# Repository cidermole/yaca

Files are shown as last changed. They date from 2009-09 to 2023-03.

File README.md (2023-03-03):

# Yaca: Yet Another CAN Automation

Low-level Home Automation software framework for 8-bit AVR microcontrollers using remote procedure calls.

## Embedded modules

* [module firmware sources](src/embedded)
* [message IDs and formats](src/embedded/ids.txt)

## PC software

Gateway and x86 services

* [CAN/TCP gateway](src/x86/yaca-gw)
* [time service](src/x86/yaca-timed)
* [remote bootloader programmer](src/x86/yaca-flash)
* [web dashboard](web)

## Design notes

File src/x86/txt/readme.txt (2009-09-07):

-> combine Switch.xml (auto-generated) and Switch1.xml (could have another name, given on command line) to an eeprom source file uint8_t EEMEM asdf[512] = { ... }; , compile and objcopy to obtain an eeprom hex. program that into node id given.

avr-gcc -mmcu=atmega8 -o test.o test.c -c
avr-objcopy -j .eeprom --set-section-flags=.eeprom="alloc,load" --change-section-lma .eeprom=0 -O ihex test.o main.eep

Bootstrap of remote call headers (RSwitch.h)
- Include a Messages.h with
	#define SendMessage(a, b)
- If remote call header file (RSwitch.h) doesn't exist yet, create...
- Compile the source (Switch.C)
- Generate the remote call headers (RSwitch.h)
- Include a normal Messages.h
- Compile again

avr-gcc -L/usr/lib/yaca RSwitch.o Switch.o ftable.o -Wl,-T linkerscript -lyaca -lyaca-client
avr-objcopy -O ihex -R .eeprom a.out a.hex

/home/david/Code/svn-yaca/yaca-x86/ycflash/trunk/build/main a.hex
/home/david/Code/svn-yaca/yaca-x86/ycflash/branches/yctr/build/main 1 0 0E

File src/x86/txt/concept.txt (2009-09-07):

todo PC
-------
- ../main Switch --> createRemoteHeader, createSendCode (gen. flash fct ptr), invoke avr-gcc on Switch.C

bootloader
----------
has unique CAN ID hardcoded in flash (separete source file generated and linked to bootloader), number should be printed (etched?) on PCB and on "case"

master
------
CAN-ID of master communication is 0x00000001 - stored in EEPROM, can be changed

if questioned (RTR master ID), master broadcasts the network ID (serial no. of master - 6 bytes)
if nodes detect a new network, the current IDs are not used but the master is informed that "new" nodes are on the bus.

the master issues CAN IDs for all incoming messages. outgoing message ids are read from eeprom too (generate config gui possibilities from commented eeprom source file?)

master may synchronize its clock to power grid frequency

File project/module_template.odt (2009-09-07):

# Module name

Generic module description: Power switch

### Technical data

Location | Kitchen
Boot-ID (6 byte hex) | de ad ca : b1 eb ad
Firmware version | 0.01 (28.08.2008)
Hardware version | 0.01 (15.08.2008)
Hardware built | 01.09.2008

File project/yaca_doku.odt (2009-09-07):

yaca

yet another CAN automation

technical manual

# Protocol definition

## General thoughts

The message-based structure of the CAN bus is used – messages are not adressed to a node, but have a number (the CAN message ID, in the following: „CANid“) identifying their usage. yaca uses extended CANids. These are assigned dynamically by the master node. The master node is used for setup, configuration and monitoring/logging, but the system must continue working even if the master fails.

In code, messages are simply implemented as C functions with a special prefix. A pre-/postprocessor then creates header files for including in code of other nodes, a function pointer table and CANid table in EEPROM for calling the functions when a message with a matching CANid is received. On the other hand, it also creates glue code in assembler to send a message when a remote message is „called“. This implements a simple RMI (remote method invocation) system which is supposed to make the code simple and logical.

avr-gcc is little-endian, but the message parameters are reversed while packing (avr-gcc rounds param adresses to 2, but the 8 bytes param of CAN messages are just too expensive for that) before transmission, the transmitted params are big-endian. On wire, any other numbers wider than 1 byte are represented as little-endian.

Despite being message-based, yaca still uses node identifiers (6-byte Boot-IDs) in configuration messages. The Boot-ID is hardcoded into the bootloader, effectively becoming a hardware address unique for each node.

## Master communication

Configuration mode is entered using messages with a special CANid, the Master-ID. The target is identified by the Boot-ID. Configuration mode simply refers to the Temp-ID being set and enabled, see below. After entering configuration mode, the node can be referred to with the Temp-ID, making it possible to transfer more bytes per CAN message.

A possibility exists to change the Master-ID (e.g. for using yaca on a CAN bus that has foreign nodes operating too), but it should not be done if not neccessary (if the Master-ID is lost, one can't enter the bootloader anymore). See Changing the Master-ID for details.

### Temp-ID association

This message is used to enter configuration mode – this is done by sending a temporary CANid (Temp-ID) to the target node which is then used for configuration messages later on. It sets a single byte of the Temp-ID at a time. If byten is 3 (4th byte), it also enables the Temp-ID. The frame is only valid if byten is between 0 and 3. The Temp-ID may only be stored in volatile memory (it must not be held after a power cycle).

CANid | 0 | 1 | 2 | 3 | 4 | 5 | 6 | 7
Master-ID | byten | data | Boot-ID
| [0;3]

Message 1: Temp-ID association

If the master node is done with the configuration, it revokes the temporary CANid.

CANid | 0 | 1 | 2 | 3 | 4 | 5 | 6 | 7
Temp-ID | 0x01 | d.c.

Message 2: Temp-ID revocation

The node then answers with:

CANid | 0 | 1 | 2 | 3 | 4 | 5 | 6 | 7
Temp-ID | 0x02 | d.c.

Message 3: Temp-ID freed up

The master may then free up the temporary CANid internally. If the node doesn't reply, the master shouldn't free up the Temp-ID. Cleaning up is performed on Bus power-off.

### Network-ID

Each node transmits a Network-ID request on bootup, except when it receives such a request from another node (in which case it must cancel the transmission to stop flooding the bus).

CANid | 0 | 1 | 2 | 3 | 4 | 5 | 6 | 7
Master-ID | 0xFF | 0x00 | d.c.

Message 4: Network-ID request

On receipt of a Network-ID request, the master node broadcasts it, except when it wants to Hard-enter a bootloader.

CANid | 0 | 1 | 2 | 3 | 4 | 5 | 6 | 7
Master-ID | 0xFF | 0x01 | Network-ID

Message 5: Network-ID broadcast

### New nodes

If a node receives a Network-ID different from the ID stored in EEPROM, it has changed bus (it is now connected to a new bus). The node doesn't react on any stored CANids but informs the master node:

CANid | 0 | 1 | 2 | 3 | 4 | 5 | 6 | 7
Master-ID | 0xFF | 0x02 | Boot-ID

Message 6: New node

The node also tells the master node its device type:

CANid | 0 | 1 | 2 | 3 | 4 | 5 | 6 | 7
Master-ID | 0xFF | 0x03 | device type

Message 7: New node device type

When the user wishes to use the node on the new bus, the master node clears the old CANids and overwrites the Network-ID in the new node:

CANid | 0 | 1 | 2 | 3 | 4 | 5 | 6 | 7
Master-ID | 0xFF | 0x04 | Boot-ID

Message 8: Format node

### Bus power-off message

Some nodes may hold status information in volatile RAM (e.g. to conserve EEPROM write cycles). When powering off the bus on purpose, this message advises all nodes to save volatile information in non-volatile memory. After powering off the bus, the master may clear all Temp-IDs in memory.

CANid | 0 | 1 | 2 | 3 | 4 | 5 | 6 | 7
Master-ID | 0xFF | 0xFF | d.c.

Message 9: Bus power-off broadcast

### Error messages

If the bootloader detects a wrong CRC after startup, it transmits a CRC error message:

CANid | 0 | 1 | 2 | 3 | 4 | 5 | 6 | 7
Master-ID | 0xFE | 0x01 | Boot-ID

Message 10: application CRC error

When the EEPROM overflows while writing the CANid data block, the node being programmed transmits a CANid data block address overflow:

CANid | 0 | 1 | 2 | 3 | 4 | 5 | 6 | 7
Master-ID | 0xFE | 0x02 | Boot-ID

Message 11: CANid data block address overflow

### Reading/writing the CANid data block

CANid data block write message:

CANid | 0 | 1 | 2 | 3 | 4 | 5 | 6 | 7
Temp-ID | 0x02 | offset | count | data

Message 12: CANid data block write

CANids are stored in the CANid data block. The flash memory contains the neccessary function pointers. When a message is received, a loop goes through the list bytewise and matches the received CANid. An entry may contain several CANids, i.e. an additional Group-ID. The number of CANids for an entry is saved as the first byte.

CANid data block example (2 message functions): 02 01 23 45 67 12 34 56 78 01 23 45 67 89

The first message function is called when either CANid 01 23 45 67 or 12 34 56 78 is received.

It is important that the master node waits for a CANid data block write done message after writing the CANid data block with one or more data block write messages.

Single CANid read command – mi is the message index, ci the CANid sub-index (when ci is 0xFF, the command reads the count of CANids associated with a message):

CANid | 0 | 1 | 2 | 3 | 4 | 5 | 6 | 7
Temp-ID | 0x03 | mi | ci | d.c.

Message 13: Single CANid read

The node sends a CANid reply:

CANid | 0 | 1 | 2 | 3 | 4 | 5 | | 6 | 7
Temp-ID | 0x04 | CANid/count (byte 1 only) | | | | | d.c.

Message 14: CANid reply

It is also possible to make a CANid data block read:

CANid | 0 | 1 | 2 | 3 | 4 | 5 | 6 | 7
Temp-ID | 0x05 | offset | d.c.

Message 15: CANid data block read

The node sends a CANid data block reply (usually returns 7 bytes, except if the read offset was larger than EEPROM-size - CANid data block size - 7):

CANid | 0 | 1 | 2 | 3 | 4 | 5 | 6 | 7
Temp-ID | 0x06 | data

Message 16: CANid data block reply

The CANid data block is cached in RAM to be able to execute fast consecutive writes. While the cache content differs from the data stored in EEPROM, a dirty flag is set in EEPROM. When the cache is completely flushed to EEPROM, the node clears the dirty flag and transmits a CANid data block write done message.

CANid | 0 | 1 | 2 | 3 | 4 | 5 | 6 | 7
Temp-ID | 0x07 | d.c.

Message 17: CANid data block write done

### Changing the Master-ID

WARNING: If you lose the new Master-ID, you can't enter the bootloader anymore.

Out of security considerations, this message only works after Hard-entering the bootloader.

CANid | 0 | 1 | 2 | 3 | 4 | 5 | | 6 | 7
Temp-ID | 0x08 | new Master-ID | | | | | d.c.

Message 18: Change Master-ID

## Bootloader

The bootloader is used to update the firmware of a node without having to open the wall, box etc. where the node is located. It is the first program started on the microcontroller, for being able to download a new firmware even when the current firmware is bad. For this purpose, the bootloader waits a few seconds for a Temp-ID association after startup (bootloader time-out). After having received that, the bootloader will not start the application except when instructed to do so (by a Temp-ID revocation).

Before starting the firmware, the bootloader also checks its CRC-checksum to ensure firmware integrity (e.g. to detect if the firmware loading was interrupted).

### Entering the bootloader

This shall work in both application and bootloader when in configuration mode ( Temp-ID association sent). When executing the application, it jumps over to the bootloader section and tells the bootloader the current Temp-ID.

CANid | 0 | 1 | 2 | 3 | 4 | 5 | 6 | 7
Temp-ID | 0x09 | d.c.

Message 19: Enter bootloader

### Hard-entering the bootloader

If the current application firmware is bad (wrong CRC or application error which prevents entering the bootloader), the master needs to hard-enter the bootloader. This is done by powering off the bus (see Bus power-off), waiting a few seconds until the buffer caps are discharged, re-applying power to the bus, waiting for the nodes to safely power up (e.g. 1 second less than bootloader time-out) and sending a Temp-ID association to enter configuration mode. As the bootloader section runs first on powerup, the bootloader can be entered even if the application is bad.

### Entering bootloader update

WARNING: If the newly programmed bootloader is not able to download a new bootloader, you have effectively locked yourself out. Check this before updating the bootloader.

WARNING: If power fails during a bootloader update (or if the bootstrap loader is running, even when not flashing), you have bricked the bootloader.

WARNING: The bootstrap loader is like a one-way street: you instantly have to download a new bootloader after having flashed it. There is no other way out that preserves the bootloader ability.

Do not use bootloader update. Never. You have been warned.

Out of security considerations, this message only works after Hard-entering the bootloader.

CANid | 0 | 1 | 2 | 3 | 4 | 5 | 6 | 7
Temp-ID | 0x0A | d.c.

Message 20: Enter bootloader update

Bootloader update is bound to a 512 Byte bootstrap program downloaded and started first, which then in turn downloads the actual bootloader. As this program must be very simple, the current version doesn't contain CAN controller initialization. Nothing useful will start after losing power. The bootstrap loader is downloaded as 8 pages. It may be located anywhere in the bootloader section (the current one has to be programmed at (relative) page 0) but must not overwrite the last 2 pages (the actual bootloader program which should never be updated). The bootloader may or may not send a Bootloader page done message after downloading the bootstrap loader.

### Programming

The application firmware memory is divided into pages. For the size of the pages or of the application flash, refer to the NDS. The memory is updated page-wise; first, select a page, then send data until the page is full. The page will automatically be programmed once all bytes are received. While programming a page, further data is ignored. After programming, the page counter will be incremented automatically; selecting further pages is only needed when leaving out pages while programming partially. When page programming is done, the node sends a Bootloader page done message.

The following message selects a page in the flash of the microcontroller:

CANid | 0 | 1 | 2 | 3 | 4 | 5 | 6 | 7
Temp-ID | 0x0B | page [le] | | d.c.

Message 21: Bootloader page select

When downloading a bootloader, page counts as an offset from the start of the bootloader section. After a page is selected (or the page counter was incremented automatically), the master node sends the page data (the data pointer is advanced by the CAN message size):

CANid | 0 | 1 | 2 | 3 | 4 | 5 | 6 | 7
Temp-ID | 0x0C | data

Message 22: Bootloader page data

When the node has finished programming the page, it sends the following message:

CANid | 0 | 1 | 2 | 3 | 4 | 5 | 6 | 7
Temp-ID | 0x0D | d.c.

Message 23: Bootloader page done

After programming, a Temp-ID revocation tells the bootloader to calculate the application CRC.

For now, the Temp-ID is stored (fix) in EEPROM – to boot the app, the bootloader sends:

CANid | 0 | 1 | 2 | 3 | 4 | 5 | 6 | 7
Temp-ID | 0x0E | d.c.

Message 24: Boot application

# Node datasheet

The node datasheet (NDS) is an XML file containing information about a specific node firmware, e.g. message functions, EEPROM size, page size etc. These are needed by the master node.

# Message index

Message 1: Temp-ID association 3

Message 2: Temp-ID revocation 4

Message 3: Network-ID request 4

Message 4: Network-ID broadcast 4

Message 5: New node 4

Message 6: New node device type 4

Message 7: Format node 4

Message 8: Bus power-off broadcast 5

Message 9: application CRC error 5

Message 10: CANid data block address overflow 5

Message 11: CANid data block write 5

Message 12: Single CANid read 6

Message 13: CANid reply 6

Message 14: CANid data block read 6

Message 15: CANid data block reply 6

Message 16: CANid data block write done 6

Message 17: Changing the Master-ID 6

Message 18: Enter bootloader 7

Message 19: Enter bootloader update 7

Message 20: Bootloader page select 8

Message 21: Bootloader page data 8

Message 22: Bootloader page done 8

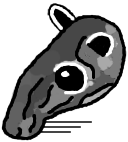
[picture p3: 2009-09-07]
project/img/yaca.png

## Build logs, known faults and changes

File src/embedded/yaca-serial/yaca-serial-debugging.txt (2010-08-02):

__vector_1: b0e - bc8 = 186 / 2 = 93 + 1 = 94 commands
  22x 1 clock-cycle command

94 * 2 - 22 = ~ 166 clock cycles

+ mcp2515_rdstatus  154
+ _read_frame  1228

= 1548 clocks    (__vector_1)
  ===========

(96.75 us @ 16 MHz)

250.000 baud ^= 40 us byte time

_spi_putc: 1/8 SPI clock of main clock -> 8 * 8 = 64 cycles (66, "gcd"(X, 3 clocks busywait)) + 5 = 71 clock cycles
                                                                                                    ===============

mcp2515_rdstatus: 12 clocks + 2 * _spi_putc (71) = 154 clocks
                                                   ==========

_read_frame: a3a - b0c = 210 / 2 = 105 + 1 = 106 commands, + for loop 637 ((20 instr + 71 _spi_putc) * 7 loops)
 47 x 1 cycle command
106 * 2 - 47 = ~ 165 clocks

+ for loop 637 (see above)
+ 6 x _spi_putc 71 = 426

= 1228 clocks
  ===========

--------------------

SPI x4   -> ~ 48 clocks per SPI byte

15 SPI bytes -> ~ 720 cycles saved, 828 remaining (103.5 us @ 8 MHz, 51.75 us @ 16 MHz)

125.000 baud ^= 80 us byte time

USART RxC interrupt (__vector_11) 722 - 76c = 74 + 2 = 76 - 6 single cycle = 70
+ fifo2_put 61

= 131 clocks  (8.19 us @ 16 MHz)
  ==========

fifo2_put: 834 - 878 = 68 + 2 = 70 - 9 single cycle = 61

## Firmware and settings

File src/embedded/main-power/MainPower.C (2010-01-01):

#include "MainPower.h"
#include "RMainPower.h"
#include <avr/io.h>
#include <avr/eeprom.h>
#include <avr/interrupt.h>
#ifndef F_CPU
#define F_CPU 8000000UL
#endif
#include <util/delay.h>
#include <inttypes.h>
#include <yaca.h>


#define OCR_VAL 200


#define ADC_U_OUT 0
#define ADC_I_IN  1
#define ADC_U_IN  2
#define ADMUX_REF ((1 << REFS1) | (1 << REFS0)) // AREF = 2.56 V


#define ST_IDLE    0
#define ST_BOOST   1
#define ST_CHARGE  2
#define ST_CHG_TOP 3


#define MILLIAMP_TO_PWM(a) (a * 255 / 100)

// TODO: soft-start (with reduced OCR_VAL) -- blew 2 A fuse without warning :-)

// PC5: red led
// PC4: green led

// PB0: charger: low-freq PWM (const. I on/off, I ~ 100 mA, we are consuming 33 mA with both LEDs)
// we are charging if we pull PB0 to 0. *do not* set PB0 to 1 (connected to base of transistor)

// PB1: PWM for step-up regulator (OC1A)

volatile uint8_t ac_power = 0, dc_maybe = 0, status_update = 0;
volatile uint16_t ac_status_scaler = 0;
volatile uint8_t charge_pwm_scaler = 0, charge_pwm = 0;
uint8_t state = ST_IDLE;
// PORTABILITY. seconds type 32-bit int overflows after 136 years, seems OK
uint32_t seconds = 0;
uint32_t chg_target = 0;
uint32_t lost_charge = 0;
uint16_t u_in, i_in;
uint8_t fifths = 0;
uint8_t no_topping = 0;

void transmit_status();

void delay_ms(uint16_t t) {
	uint16_t i;
	for(i = 0; i < t; i++)
		_delay_ms(1);
}

void red_led(uint8_t i) {
	if(i)
		PORTC |= (1 << PC5);
	else
		PORTC &= ~(1 << PC5);
}

void red_led_toggle() {
	PORTC ^= (1 << PC5);
}

void green_led(uint8_t i) {
	if(i)
		PORTC |= (1 << PC4);
	else
		PORTC &= ~(1 << PC4);
}

uint16_t adc_convert(uint8_t channel) {
	ADMUX = (channel & 0x07) | ADMUX_REF; // select channel (+ keep reference)
	ADCSRA |= (1 << ADSC) | (1 << ADIF); // start conversion, clear int flag
	while(!(ADCSRA & (1 << ADIF))); // wait for conversion

	return ADCW;
}

void adc_init() {
	ADMUX = (1 << REFS1) | (1 << REFS0);
	ADCSRA = (1 << ADEN) | (1 << ADPS2) | (1 << ADPS1); // enable ADC, prescaler = 64 (8 MHz / 64 = 125 kHz, 13 cycles per conversion ~ 100 us conversion)
	delay_ms(100); // wait for ADC to warm up
	adc_convert(0); // dummy conversion
}

void transition_idle() {
	transmit_status();
	charge_pwm = MILLIAMP_TO_PWM(35); // we consume 33 mA from battery at all times, 2 mA reserved
	red_led(0);
	green_led(1);
	state = ST_IDLE;
}

void transition_boost() {
	charge_pwm = 0; // if boosting, we have no AC - don't waste our own power
	red_led(1);
	green_led(0);
	state = ST_BOOST;
}

void transition_charge() {
	charge_pwm = MILLIAMP_TO_PWM(100); // charge with (100 - 33) = 67 mA
	yc_prepare(2008);
	yc_send(MainPower, Debug1(lost_charge));
	if((lost_charge >> 16) < 22) { // if discharge was less than 10 %, omit the topping
		no_topping = 1;
	} else {
		no_topping = 0;
	}
	chg_target = seconds + (lost_charge >> 16) * 459;
	yc_prepare(2009);
	yc_send(MainPower, Debug2(chg_target));
	red_led(1);
	green_led(1);
	state = ST_CHARGE;
}

void transition_chg_top() {
	if(no_topping) {
		transition_idle();
		return;
	}

	// low charging current is supposedly bad for batteries, so topping charge with the full current (C/28 anyways...)
	charge_pwm = MILLIAMP_TO_PWM(100); // charge with (100 - 33) = 67 mA
	chg_target = seconds + 1200; // 20 min * 67 mA = 22 mAh (1,2 %)
	green_led(1);
	// red led is blinking
	state = ST_CHG_TOP;
}

// recalculate_charge(): we were charging and lost power... recalculate lost_charge
void recalculate_charge() {
	lost_charge = (((chg_target - seconds) * 1713) / 3072) * 256;
}

void transmit_status() {
	uint8_t t_high = 0;
	uint16_t t = 0;
	
	if(state == ST_CHARGE || state == ST_CHG_TOP) {
		t_high = (chg_target - seconds) >> 16;
		t = (chg_target - seconds) & 0xFFFF;
	} else if(state == ST_BOOST) {
		t_high = lost_charge >> 16;
		t = lost_charge & 0xFFFF;
	}
	
	yc_prepare_ee(YC_EE_POWERSTATUS_ID);
	yc_send(MainPower, PowerStatus(state, u_in, i_in, t_high, t));
}

int main() {
	uint8_t tenth_count = 0;

	DDRC |= (1 << PC5) | (1 << PC4);
	DDRB |= (1 << PB1) | (1 << PB0);
	ACSR = (1 << ACBG); // Analog Comp: + is bandgap ref. = 1,23 V

	ICR1 = 256;
	TCCR1A = (1 << WGM11); // 8-bit
	TCCR1B = (1 << WGM13) | (1 << WGM12) | (1 << CS10); // prescaler 1, fast pwm
	TIMSK |= (1 << TOIE1);
	OCR1A = OCR_VAL;

	sei();
	
	ac_power = 1; // optimism rules!
	adc_init();
	
	transition_idle();
	
	while(1) {
		switch(state) {
		case ST_IDLE:
			if(!ac_power)
				transition_boost();
			break;

		case ST_BOOST:
			if(ac_power) {
				transition_charge();
			}
			break;

		case ST_CHARGE:
			if(!ac_power) {
				recalculate_charge();
				transition_boost();
				break;
			}
			if(seconds > chg_target)
				transition_chg_top();
			break;

		case ST_CHG_TOP:
			if(!ac_power) {
				transition_boost();
				break;
			}
			if(seconds > chg_target)
				transition_idle();
			break;

		default:
			break;
		}
		
		if(status_update) { // every 100 ms
			if(++tenth_count == 10) {
				seconds++;
				tenth_count = 0;
				
				if(state == ST_CHG_TOP) {
					red_led_toggle();
				}
			}
			
			u_in = adc_convert(ADC_U_IN);
			i_in = adc_convert(ADC_I_IN);
			
			if(state == ST_BOOST)
				lost_charge += i_in;
			
			if(++fifths == 2) {
				if(state != ST_IDLE)
					transmit_status();
				fifths = 0;
			}
			status_update = 0;
		}
		
		yc_dispatch_auto();
	}
	return 0;
}

void DM(Charge(uint8_t t_high, uint16_t t)) {
	transition_charge();
	chg_target = seconds + (((uint32_t) t_high) << 16) + t;
	transmit_status();
}

void DR(PowerStatus()) {
	transmit_status();
}

void enter_bootloader_hook() {
	cli();
	TCCR1A = 0;
	TCCR1B = 0;
	TCNT1 = 0;
	TIMSK = 0;
	DDRB &= ~(1 << PB0); // stop charging
	PORTC &= ~(1 << PC4); // green off
	PORTC &= ~(1 << PC5); // red off
	yc_bld_reset();
}

ISR(TIMER1_OVF_vect) {
	if(ACSR & (1 << ACO)) {
		TCCR1A |= (1 << COM1A1);
		dc_maybe = 1;
	} else {
		TCCR1A &= ~(1 << COM1A1);
	}
	
	if(ac_power) { // software PWM
		charge_pwm_scaler++;
		
		if(charge_pwm_scaler == 0) // 256 -> every 8.2 ms (122 Hz)
			DDRB |= (1 << PB0);
		
		if(charge_pwm_scaler == charge_pwm)
			DDRB &= ~(1 << PB0);
	} else {
		DDRB &= ~(1 << PB0);
	}
	
	if(++ac_status_scaler == 3125) { // every 100 ms, update AC status
		ac_status_scaler = 0;
		ac_power = !dc_maybe;
		dc_maybe = 0;
		status_update = 1;
	}
}

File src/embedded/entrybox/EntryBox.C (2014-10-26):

#include "EntryBox.h"
#include "REntryBox.h"
#include <stdint.h>
#include <yaca.h>
#include <avr/io.h>
#include <avr/interrupt.h>

#ifndef INT32_MAX
#define INT32_MAX 0x7fffffffL
#endif

/*

PB1 (OC1A): charge pump for opamps
PD0: radar sensor supply (N-channel MOSFET gate) TODO: power
PD1: battery charger from CAN-bus power to battery, /EN of LM2576
PD5: photo camera (N-channel MOSFET gate)
PD6: dummy load (N-channel MOSFET gate)
PD7: radar sensor input, pulling vs. GND

ADC0: IBAT (battery current), 6.5 mA resolution
ADC1: VBAT (battery voltage), 15 mV resolution
ADC2: ISOL (solar [charge] current), 3.25 mA resolution

  |
  v IBAT
+ |
-----  12 V lead-acid battery
 ---
  |



coulomb counter
---------------
basic resolution: U = 15 mV, I = 6.5 mA, P = 97.5 uW (microwatt)

ADC low-pass filter tau = 2 ms -> 10 ms changes relevant -> 100 Hz samplerate

12 V 7 Ah capacity fits into 32 bit
1 year's worth of microjoules don't fit

~ 10256 P units equal 1 Watt
1 year's worth of Joules fit. -> energy counting in Joules


*/

#define ADC_IBAT 0
#define ADC_VBAT 1
#define ADC_ISOL 2

#define ADMUX_REF ((1 << REFS1) | (1 << REFS0)) // internal AREF = 2.56 V with external cap

#define VBAT_REL_ERROR (-0.01) // measured and calculated
#define DUMMY_OFF_THRESHOLD_V ((uint16_t) (12.9 / 0.015 * (1+VBAT_REL_ERROR)))
#define DUMMY_ON_THRESHOLD_V ((uint16_t) (12.5 / 0.015 * (1+VBAT_REL_ERROR)))

#define CHARGE_OFF_THRESHOLD_V ((uint16_t) (13.6 / 0.015 * (1+VBAT_REL_ERROR)))
#define CHARGE_ON_THRESHOLD_V ((uint16_t) (12.1 / 0.015 * (1+VBAT_REL_ERROR)))

#define JOULE_100_PUNITS 1025641L
#define JOULE_BATTERY_FULL (12 * 7 * 3600UL)
#define MAXIMUM_POWER_OUTPUT 42 // 42: 14 V * 3 A, the expected maximum output power

void enter_bootloader_hook() {
	TCCR1A = 0;
	TCCR1B = 0;
	TCCR2 = 0;
	TIMSK = 0;
	cli();
	yc_bld_reset();
}

void init_timers() {
	OCR1A = 100; // 2 MHz / 100 = 20 kHz toggle -> 10 kHz frequency generator
	TCCR1A = (1 << COM1A0); // toggle OC1A on compare match
	TCCR1B = (1 << WGM12) | (1 << CS10); // CTC mode, top = OCR1A, prescaler = 1

	OCR2 = 156; // 2 MHz / (156 * 128) = ~ 100 Hz
	TCCR2 = (1 << WGM21) | (1 << CS22) | (1 << CS20); // CTC mode, prescaler = 128

	TIMSK = (1 << OCIE2); // enable Timer2 compare match interrupt
}

void init_adc() {
	ADMUX = ADMUX_REF; // Vref = internal 2.56 V with external cap
	ADCSRA = (1 << ADEN) | (1 << ADPS2); // ADC prescaler = 16 -> 2 MHz / 16 = 125 kHz
}

void init_ports() {
	DDRB |= (1 << PB1); // config OC1A as output (charge pump)
	DDRD |= (1 << PD6) | (1 << PD5) | (1 << PD1) | (1 << PD0); // dummy, camera, emergency charger, radar power
	PORTD |= (1 << PD7) | (1 << PD5) | (1 << PD1) | (1 << PD0); // PD7: motion relay: input with pullup, PD5: photo trigger (phone charger), PD1: emergency charger off, PD0: radar power perm. on for now
	//PORTD &= ~(1 << PD1); // temp: enable charger
}

int16_t adc_convert(uint8_t channel) {
	ADMUX = (channel & 0x07) | ADMUX_REF; // select channel (+ keep reference)
	ADCSRA |= (1 << ADSC) | (1 << ADIF); // start conversion, clear int flag
	while(!(ADCSRA & (1 << ADIF))); // wait for conversion
	return ADCW;
}

/**
 * This might be overkill, but group 4 reads together, and poll CAN inbetween (4 * 14 < 67) (shortest CAN frame: 67 bit times of 125 kHz CAN bitrate)
 */
int16_t adc_convert_avg(uint8_t channel) {
	uint8_t i, j;
	int16_t sum = 0; // 2^10 ADC resolution * (2^5 = 32 reads) possible before overrun in 16-bit signedness

	// instead of using adc_convert(), just select the channel once here.
	ADMUX = (channel & 0x07) | ADMUX_REF; // select channel (+ keep reference)

	for(j = 0; j < 8; j++) {
		for(i = 0; i < 4; i++) {
			// 8 * 4 = 32 samples average
			ADCSRA |= (1 << ADSC) | (1 << ADIF); // start conversion, clear int flag
			while(!(ADCSRA & (1 << ADIF))); // wait for conversion
			sum += ADCW;
		}
		yc_dispatch_auto();
	}

	return sum / 32;
}

int16_t ibat_offset = 538; // Ibat offset from calculations
int16_t ibat;
uint16_t vbat, isol;
int32_t sum_punit = 0;
uint32_t sum_punit_solar = 0;
uint32_t joule_battery = JOULE_BATTERY_FULL;
uint32_t joule_solar = 0;

uint32_t count = 0; // car count

uint8_t cam_force = 1; // 0: force off, 1: auto, 2: force on
uint8_t charger_force = 1; // 0: force off, 1: auto, 2: force on
uint8_t photo_trig = 0;
uint8_t daylight = 1; // whether it makes sense to make photos (only when it's bright)

void time_tick();
uint8_t dummy_status();

void photo_tick() {
	static uint8_t state = 0;
	static uint16_t count = 0;

	switch(state) {
	case 0:
		if(photo_trig && cam_force == 1) {
			PORTD &= ~(1 << PD6); // turn mobile charger off -> take photo signal
			PORTD &= ~(1 << PD5); // turn mobile charger off -> take photo signal
			count = 0;
			state = 1;
		}
		break;
	case 1:
		if(++count == 500) { // 1 second off
			if(cam_force == 1) {
				PORTD |= (1 << PD6); // turn mobile charger on again
				PORTD |= (1 << PD5); // turn mobile charger on again
			}
			state = 0;
			photo_trig = 0;
		}
		break;
	}
}

void debounce_count_tick() {
	static uint8_t state = 0;

	switch(state) {
	case 0:
		if(bit_is_clear(PIND, PD7))
			state = 1;
		break;
	case 1: // glitch filter
		if(bit_is_clear(PIND, PD7)) {
			state = 2;
			if(daylight)
				photo_trig = 1;
			count++;
			yc_status(Count);
		} else
			state = 0;
		break;
	case 2: // relay on
		if(bit_is_set(PIND, PD7))
			state = 3;
		break;
	case 3: // glitch filter (relay on)
		if(bit_is_set(PIND, PD7))
			state = 0;
		else
			state = 2;
		break;
	default:
		state = 0;
	}
}

void conversion_tick() {
	static uint8_t time = 0;
	int32_t power;
	/*uint16_t*/ vbat = adc_convert_avg(ADC_VBAT);
	/*int16_t*/ ibat = adc_convert_avg(ADC_IBAT) - ibat_offset;

	power = ((int32_t) vbat) * ibat;
	sum_punit += power;
	sum_punit_solar += (uint32_t) ((uint32_t) vbat) * isol;

	isol = adc_convert_avg(ADC_ISOL) / 2; // 3.25 mA -> 6.5 mA resolution

	if(++time == 100) {
		time_tick();
		time = 0;
	}
}
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

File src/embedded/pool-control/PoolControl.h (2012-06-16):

#include "Messages.h"
#include <inttypes.h>

#define YC_EE_PHSTATUS_ID YE(508) // int32
#define YC_EE_TEMPSTATUS_ID YE(504) // int32
#define YC_EE_PUMP_FROM_HOUR YE(503) // int8
#define YC_EE_PUMP_TO_HOUR YE(502) // int8
#define YC_EE_RELAYSTATUS_ID YE(498) // int32
#define YC_EE_PH_OFFSET YE(496) // int16

namespace PoolControl {
	void HDS(PhStatus(uint16_t ph_centi));
	void HDR(PhStatus());
	void HDS(TempStatus(int16_t temp_deci));
	void HDR(TempStatus());
	void HDS(RelayStatus(uint8_t pump_on));
	void HDR(RelayStatus());

	void HDM(Time(uint8_t hour, uint8_t min, uint8_t sec, uint16_t year, uint8_t month, uint8_t day, uint8_t flags));
	void HDM(SetMode(uint8_t mode));
	void HDM(SetRelay(uint8_t status));
}

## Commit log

2009-09-07 improved yaca-flash, added TODO, corrected libyaca (INT0/1)
    [main.c]
2009-09-07 yaca-program: fixed minor mistake with empty canids
    [main.cpp]
2009-09-07 more fixes; now it segfaults - doh! - gn8
    [main.cpp]
2009-09-08 yaca-program: fixed segfault; XmlTree: fixed text parsing
    [main.cpp]
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2009-09-08 yaca-c, yaca-hexmerge: yaca-c on -new now merges bootloader and app together for flashing; yaca-serial: fixed linkerscript (hopefully it's okay now)
    [main.cpp]
2009-09-08 XmlTree: fixed a bug with <tag/>s closing themselves; yaca-c: added -save-temps option
    [main.cpp]
2009-09-08 XmlTree: fixed; testcode: Switcha
    [main.cpp]
2009-09-09 yaca-cached: now hopefully fixed
    [main.cpp]
2009-09-09 yaca-cached: fixed once again
    [main.cpp]
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2009-09-20 added eagle files: base board design, switch-beep
    [switch-beep.brd, switch-beep.sch, yaca-base.brd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]
2009-09-20 eagle: switch-beep
    [switch-beep.brd]
2009-09-25 Revert "eagle: switch-beep"
    This reverts commit 96dbffa27b98b889ca9f08c605cb6e1d4ffce85f.
    [switch-beep.brd]
2009-09-25 Revert "Revert "eagle: switch-beep""
    This reverts commit 23a02ae51b6558eed21cfdc41e49aab41c5b559b.
    [switch-beep.brd]
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2009-12-08 main-power: fixed LEDs. bootloader F_CPU needs to be adapted for main-power.. but then still unstable... sends too much page done responses ... wth... gn8
    [MainPower.C]
2009-12-10 yaca-tr: fixed msg.info = 0
    [main.c]
2009-12-10 yaca-gw: corrected dangerous buffer size, fixed error
    [main.c]
2009-12-12 yaca-serial: probably, too large UART buffers caused a stack overflow
2009-12-12 yaca-serial: (hopefully) fixed (a) (double-transmission) transmission bug
    [yaca-serial.c]
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2009-12-12 x86 yaca tools (except yaca-cached *TODO*): read_message() from socket improved
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2009-12-12 main-power: added mpmon, simple monitoring of AC status (prototype)
2009-12-13 yaca-serial: bugfix: 0x55 wasn't transmitted correctly
    [yaca-serial.c]
2009-12-13 libyaca: enter_bootloader_hook() for the application to be able to hook (specifically implemented for main-power)
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2009-12-13 main-power: reworked code, new: state machine
    [MainPower.C]
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2009-12-16 main-power: minor changes for CAN-ID from EEPROM, web: main-power.class.php with status, U and I display. untested.
2009-12-16 main-power: fixed compile error
2009-12-18 web/main-power: fixed number_format() error
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2009-12-19 web/main-power: small info correction
2009-12-19 web/main-power: small info correction2
2009-12-19 web/main-power: small info correction3
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2009-12-19 web/main-power: corrected(?) charge function
2009-12-19 main-power: corrected Charge
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2009-12-19 main-power: fixed self-PWM artifact
    [MainPower.C]
2009-12-20 Revert "returned Makefiles" -> Makefiles at 8 MHz again for main-power
    This reverts commit 3d7bbf4a910d0a2b9ae53db052ec42e7fc358156.
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2009-12-20 yaca-cached: quit on yaca-serial socket error
    [main.cpp]
2009-12-26 TODO; ids; testcode (id from eeprom); main-power (ids)
2009-12-28 yaca-time: compile + link error
    [main.cpp]
2009-12-28 yaca-time: fixed year 2
    [main.cpp]
2009-12-29 yaca-serial: time source fixes
    [yaca-serial.c]
2009-12-29 yaca-serial: fixed message type
    [yaca-serial.c]
2009-12-29 yaca-time: read buffer overflow prevention
    [main.cpp]
2009-12-29 testcode: removed Switch (replaced by Switcha)
2009-12-29 yaca-c, testcode, main-power: moved linker script to yaca-c directory
2009-12-30 yaca-cached: fixed endless-loop bug introduced by uniting network code
    [main.cpp]
2009-12-30 yaca-serial: correction factor, DST (CEST/CET switch)
    [yaca-serial.c]
2009-12-30 yaca-serial: fixed year, changed year to 16-bit
    [yaca-serial.c]
2009-12-30 yaca-cached: fixed no-transmission bug
    [main.cpp]
2009-12-30 yaca-serial.c: now (hopefully) corrected time
    [yaca-serial.c]
2009-12-30 yaca-timed: no buffer reading, causes hang problems
    [main.cpp]
2009-12-30 yaca-serial: now probably fixed drift and sync?
    [yaca-serial.c]
2009-12-31 main-power: no topping charge if discharge < 10 %
2010-01-01 yaca-serial: now resettable over CAN-ID 3
    [yaca-serial.c]
2010-01-01 yaca-serial: fixed message "swallowing"
    [yaca-serial.c]
2010-01-01 main-power: now transmits status update on getting idle (stops yaca-cached from showing old charge data)
2010-01-01 Revert "Merge branch 'master' into main-power"
    This reverts commit 9bfd38716fca73bd84a1a2e9d29294775f108da9, reversing
    changes made to e576afb9260d5ef24a78041cb3f5c7ad7fa96dc5.
2010-02-11 geda: started heating control
    [heating.sch]
2010-02-13 geda heating: switching regulator, can bus coupler
    [heating.sch]
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2010-02-14 geda heating: schematics (almost) completed, todo: CS of MCP2515
    [heating.sch]
2010-02-14 geda heating: crystal. TODO: CS of MCP2515
    [heating.sch]
2010-02-14 geda heating: corrected footprints of L2 and Q1; generated layout file
    [heating.sch]
2010-02-14 geda heating: fixed tantalum caps (C7-C9) footprint
    [heating.sch]
2010-02-14 geda heating: added CS of mcp2515, layouted mcp2515 + atmega128
    [heating.sch]
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2010-06-02 geda: added pool
    [pool.sch]
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2010-06-29 yaca-c: added -mmcu switch to linker - needed for new style eeprom functions
2010-06-29 pool-control: doubled inverter charge-pump frequency (circuit: 10 ohm on 1u caps) - now reaches ~ -3 V
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2010-06-30 pool-control: relay test: compile error fix
    [PoolControl.C]
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2010-07-14 pool-control: now switches on relay on startup if we are between start and end times
2010-07-14 pool-control: measure_temp() now always waits 800 ms regardless of a sensor being connected
2010-07-14 pool-control: one-wire now releases the hard pulling, check hardcoded for now
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2010-07-15 pool-control: calculate mean of 64 measurement points to filter output values
2010-07-15 pool-control: SetMode now toggles between raw and filtered mode
2010-07-15 pool-control: fixed compiler warnings
    [PoolControl.C]
2010-07-16 heating: cleaned up schematic, needs atmega8
    [heating.sch]
2010-07-16 heating -> control-panel
    [heating.sch]
2010-07-16 control-panel: inserted atmega8
    [heating.sch]
2010-07-16 control-panel: added voltage regulator
    [heating.sch]
2010-07-16 control-panel: new start, removed pcb, fixed atmega8 footprint
    [heating.sch]
2010-07-16 heating.sch -> controlpanel.sch
    [controlpanel.sch]
2010-07-16 control-panel: half-placed components, first go at routing
    [controlpanel.sch]
2010-07-16 control-panel: more routing
    [controlpanel.sch]
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2010-07-17 yaca-serial: fixed uart.h not having uart_init() ubrr parameter *stunned*
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2010-07-18 yaca-ppp: fixed compile errors
    [main.cpp]
2010-07-25 pool-control: 1 sec of pump switching extended to a 5 sec slot (should be more reliable now)
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2010-07-27 pool-control: fixed ow_read() for one-wire
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2010-07-28 yaca-serial: added mechanism for reporting data jam
    [yaca-serial.c]
2010-07-28 yaca-serial: bus-off handling (~ 300 ms timeout of single CAN frame tx), added hysteresis to rx buffer, increased rx buffer to 200 bytes
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2010-07-30 yaca-gw: fixed problem where get_sender() returned the UART fd, which was then handled like a socket client
    [main.c]
2010-08-01 yaca-gw: fixed SIGPIPE occuring and killing the process
    [main.c]
2010-08-01 yaca-timed: fixed read buffer overflowing
    [main.cpp]
2010-08-02 control-panel: enabled pull-up on rxd (prevents 0x00 spamming), reduced baudrate to 57600 (works, *yay*)
    [ControlPanel.C]
2010-08-02 control-panel: reduced to 38400 baud, added buffer aggregation (not working yet)
    [ControlPanel.C]
2010-08-02 control-panel: added temp sensor, major restructuring - mainloop content put into a function
2010-08-02 control-panel: fixed compile erros
    [ControlPanel.C]
2010-08-02 control-panel: fixed one-wire pin
2010-08-02 control-panel: set uart baud rate in eeprom (makes stuff easier, as the bootloader isn't working properly)
2010-08-02 control-panel: fixed resetting of temp sensor
    [ControlPanel.C]
2010-08-02 control-panel: fixed ow_read() for one-wire
2010-08-02 libyaca-bl: accelerated SPI to MCP2515 by 4 times
2010-08-02 yaca-serial: don't transmit XON/XOFF for now (doesn't work on Pocket PC)
    [yaca-serial.c]
2010-08-02 pool-control: don't store pump_from and pump_to in RAM; read them from EEPROM every time
2010-08-02 pool-control: fixed compile error
    [PoolControl.C]
2010-09-05 radio-base: created; RFM12 base station for receiving temperature
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2010-09-06 radio-base: added sender (transmitter aka RFM12 temp sensor)
2010-09-14 added main-power schematics (fresh start)
    [main-power.sch]
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2010-09-14 gschem main-power: added power connector and fuse, began ZVS
    [main-power.sch]
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2010-09-26 yaca-ppp: check periodically for pppd and restart if neccessary (reconnect fix)
    [main.c]
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2010-09-26 main-power geda: started redesign of power converter
    [main-power.sch]
2010-09-26 yaca-ppp: fixed compile error
    [main.c]
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2010-10-18 libradio: fixed fc (framecounter) handling; added CRC calc to test
2010-11-13 yaca-cached: start listening for ID even if it failed for the first time
    [main.cpp]
2010-11-17 yaca-cached: now answers directly instead of timeout after failcounter has been reached
    [main.cpp]
2010-11-17 yaca-cached: fixed message info not telling timeout
    [main.cpp]
2010-11-20 libradio: source files stripped of debug printouts and x86 CRC stuff
2010-11-20 radio-base/sender2: reverted to original sender
    [main.c]
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2010-11-20 librfm12: removed sleep() / use timer(); wake() extended with delay
2010-11-20 libradio: added radio_retransmit() which doesn't increment frame counter
2010-12-08 radio-base sender2: rewrite? git problems? (really just removed time_sync() - moved to own file, fixed radio_init() and the rf12 sleep to wait delay_big instead of hardcoded value
    [main.c]
2010-12-08 radio-base sender2: stitched everything together, fixed rfm12_phy.h missing semicolon
    [main.c]
2010-12-08 radio-base sender2: don't break retransmission loop on ack rx error
    [main.c]
2010-12-09 libradio, librfm12: master doesn't need to init some SPI pisn, but slave DOES
2010-12-12 radio-base, libradio, librfm12: RFM12 interrupt fixed
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2011-01-05 yaca-ppp: inserted 10 s loop to prevent endless-pppd spawn
    [main.c]
2011-02-19 radio-base/libradio: moved sensor to slot 200 (30 s)
2011-02-22 libtimesync: test stripped down to 0 filter and 0 feedback
2011-02-22 libtimesync: begin rewrite for third (hopefully last) core - filter needs sign
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2011-02-24 eagle: yaca-base v0.1 added
    [switch-beep.brd, switch-beep.sch, yaca-base.brd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]
2011-02-24 eagle: yaca-base: filled holes
    [yaca-base.brd]
2011-02-26 time: fixed timer compare value, fixed error handling
    [Time.C]
2011-02-26 time: now resets static stuff in dcf_dispatch_bit() correctly
    [Time.C]
2011-02-27 time: fix compiler warning
    [Time.C]
2011-02-27 time: rework in progress (adding local counters)
    [Time.C]
2011-02-28 time: fixed compiler errors
    [Time.C]
2011-03-10 time: midnight counter reset
    [Time.C]
2011-03-10 time: fixed interrupt-based time sync
    [Time.C]
2011-03-12 yaca-serial: fixed time updates every 125 ms, uart 2X bit removed
    [uart.c, yaca-serial.c]
2011-03-13 time: production use (id 401), debug msg 799 -> 796 (799 used by radio-base to report deviation); deleted ROADMAP.txt (replaced by TODO)
    [Time.C]
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2011-05-14 car-counter: fixed timer
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2011-06-15 web/pool-control: only display pH correction suggestions if the relay is actually on
2011-08-28 fixed build for avr-gcc 4.6.1
    [main.c]
2011-09-04 entrybox: activate ADC (Aref), generate 10 kHz for charge pump
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2011-10-03 libyaca-bl: mcp2515 driver: optimize code size by setting less registers
    * no standard frames expected on bus - omit filtering in MCP2515 regs and error checking
    * no need to write values to regs BFPCTRL, TXRTSCTRL because these are correct on POR
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2011-10-04 libyaca-bl: pulled out SPI code from mcp2515.c to its own file spi.c (should make it easier to port)
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2011-10-09 web: temp.class.php: fixed display of negative temperature
2011-10-30 yaca-flash: fix output when in -crc mode (broke yaca-c)
    [main.cpp]
2011-10-30 bootloader: fixed bootloader tx'ing its signature all the time ('{' closing the wrong switch)
2011-10-30 eagle: added can4wrt
    [can4wrt.brd, can4wrt.sch]
2011-10-30 eagle: added motiontest
    [motiontest.brd, motiontest.sch]
2011-10-30 eagle: added ycpower
    [ycpower.brd, ycpower.sch]
2011-10-30 eagle: added octopus-breakout
    [breakout.brd, breakout.sch]
2011-10-30 geda: added base-board
    [baseboard.sch]
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2012-01-03 scripts/post-mortem.sh: read out AVR flash, eeprom and fusebits after a node has died, for later analysis
2012-05-05 EntryBox: added documentation of radar sensor input pin
2012-05-05 yaca-serial/uart.*: replaced deprecated prog_char by const char; bootloader.hex added
    [uart.c]
2012-05-10 EntryBox: fixed Isol (divide by 2)
    [EntryBox.C]
2012-06-16 entrybox: switch on dummy load if there is too much voltage
    [EntryBox.C]
2013-02-09 reset EntryBox Ibat offset - it's fine this way
    [EntryBox.C]
2013-02-09 EntryBox: average ADC measurements, correct relative error of Vbat at 22 deg C
    [EntryBox.C]
2013-10-12 added charger control to EntryBox (some weeks/months ago?)
2013-11-23 2013-10-14 EntryBox: rewired charger FET gate, changed charging logic
2013-11-23 entrybox: avoid taking photos at night
    [EntryBox.C]
2013-12-18 web: added img/settings.png
    original screwdriver image licensed CC-BY-SA by kyo-tux (Asher) at deviantart,
    http://kyo-tux.deviantart.com/
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
